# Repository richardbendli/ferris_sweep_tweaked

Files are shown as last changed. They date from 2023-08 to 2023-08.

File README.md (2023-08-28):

# Tweaked Ferris Sweep

A fork of [David Barr's Sweep](https://github.com/davidphilipbarr/Sweep).

| Front | Back |
| :---: | :---: |
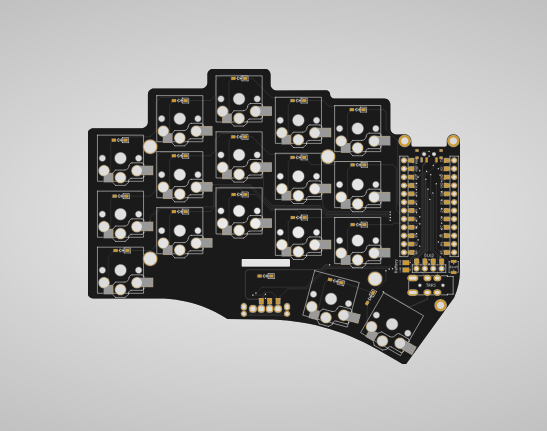
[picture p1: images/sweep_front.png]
front
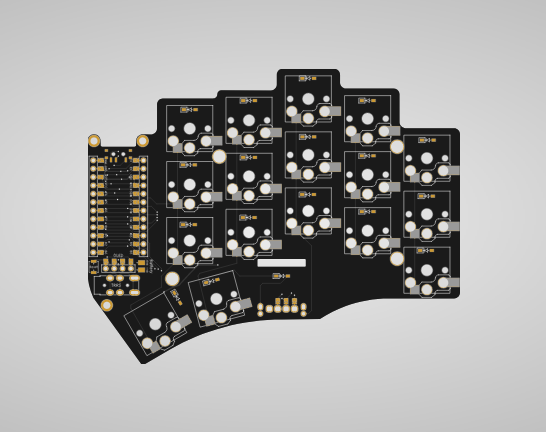
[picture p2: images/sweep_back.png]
back
|  |  |
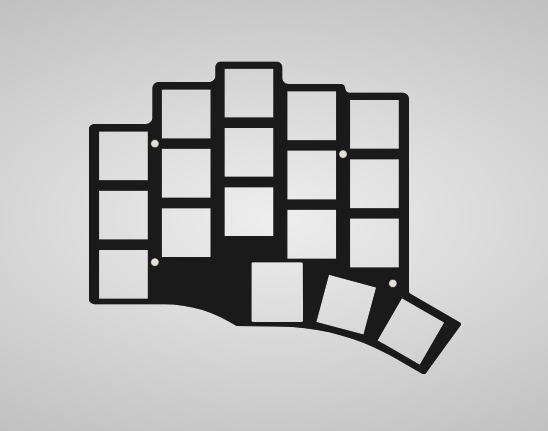
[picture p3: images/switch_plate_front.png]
front
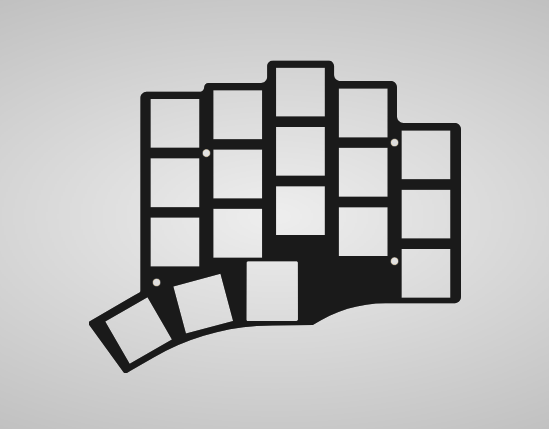
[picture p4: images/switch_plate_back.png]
back
|  |  |
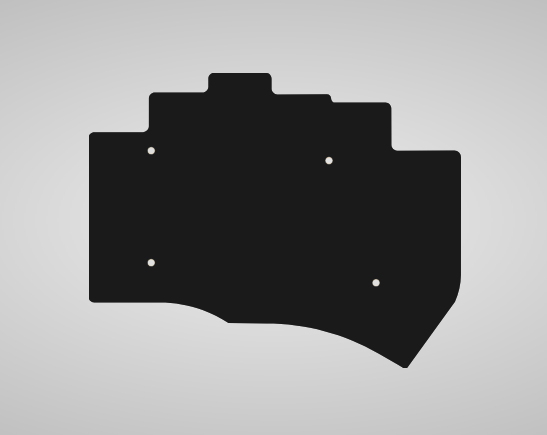
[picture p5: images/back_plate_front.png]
front
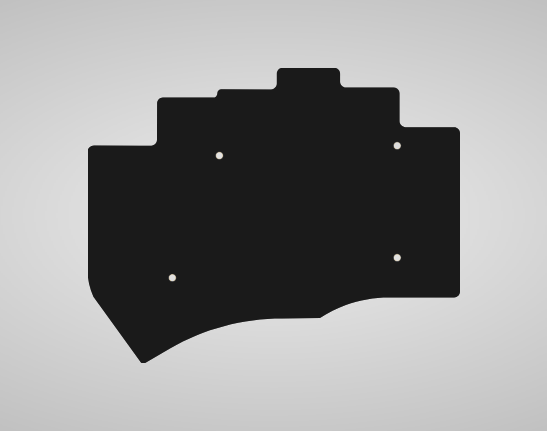
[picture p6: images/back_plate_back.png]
back
|  |  |

### Features

* Low profile Kailh Choc switches
* Hotswap
* Dual side-scrolling encoder
* Oled screens
* Power switch for battery management
* Bluetooth support w/ nice!nano
* Plate style case with mcu cover

### Components list

To build and use this Ferris Sweep you will need:

* 1 × PCB Kit (1.6mm thickness is good)
* 1 × back plate kit (optional, you can go for 1.2mm thickness)
* 2 × promicro compatible boards ( I used the Elite C ) or 2 x nice!nanos.
* 34 × Kailh Choc v1 switches
* 34 × Kailh Choc hotswap sockets (PG1350)
* 34 × keycaps
* 2 × side-scrolling encoders EVQWGD001
* 2 × OLED LCD Display 128x32 SSD1306 (optional)
* 2 × reset switches (optional; B3U-1000P(M))
* Some little rubber feet/bumpers (a minimum of 4 on each side)
* 2 × power switches (wireless only; MSK 12C02)
* 2 × lipo batteries (wireless only; 301230 or 301228)
* 1 × TRRS (not TRS!) cable (wired only)
* 2 × TRRS Jack [PJ-320A] (wired only)
* 1 × USB Cable (depends on your micro-controller choice)

##

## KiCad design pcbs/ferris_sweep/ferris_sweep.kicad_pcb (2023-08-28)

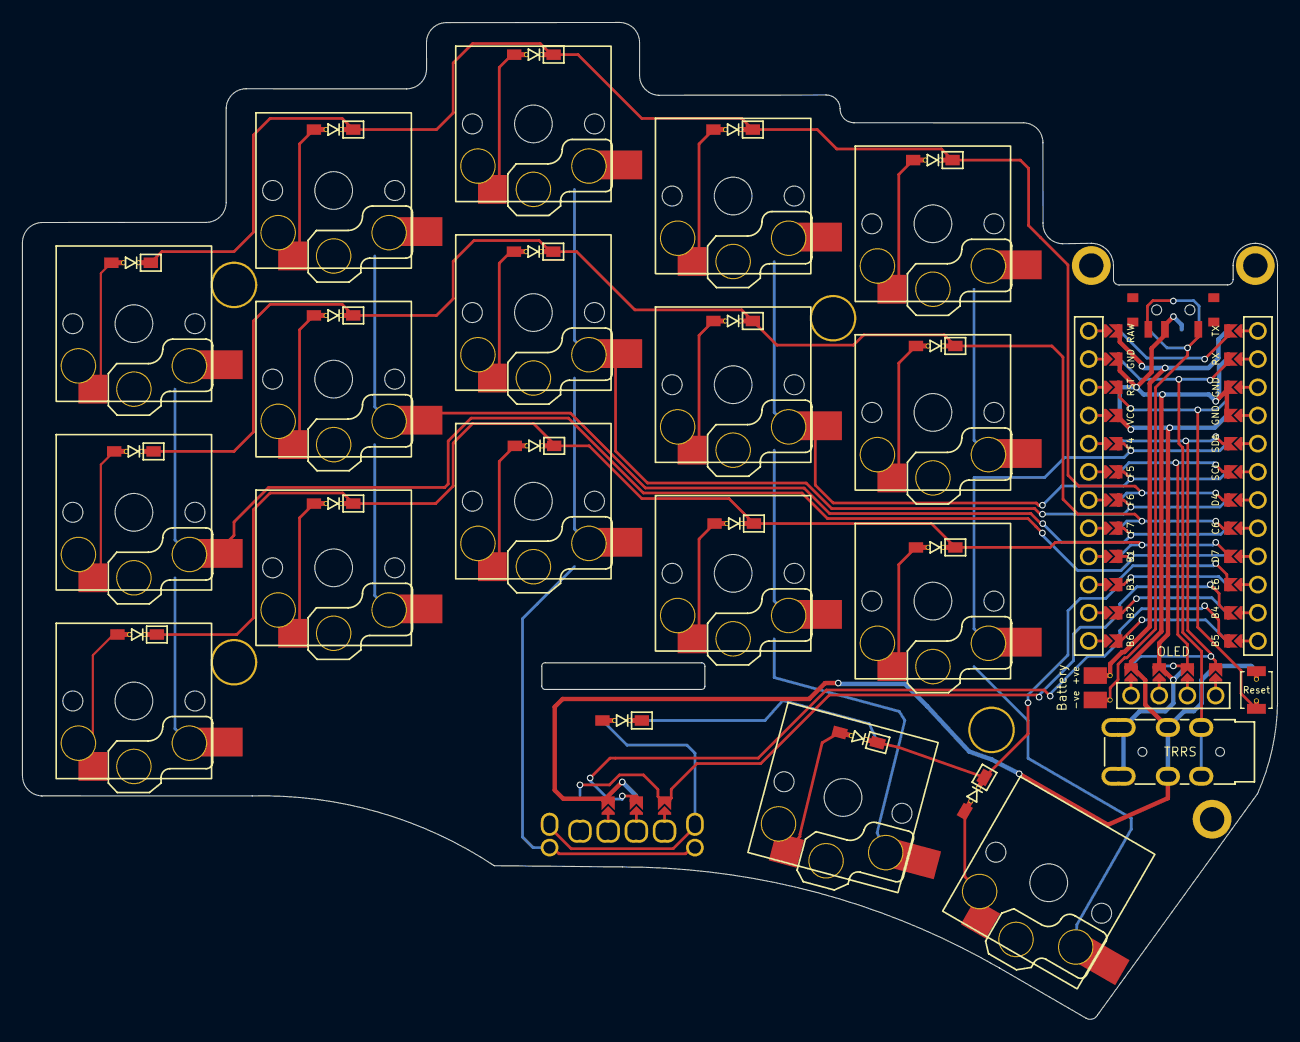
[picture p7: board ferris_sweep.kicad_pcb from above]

Board: 2 copper layers, 113.1 x 89.8 mm, 49 parts (0 on the bottom side), 22 nets.

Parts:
BT1: Battery; Battery_pads_reversible
D1, D2, D3, D4, D5, D6, D7, D8, D9, D10, D11, D12, D13, D14, D15, D16, D17: 1N4148W; D3_SMD
ED1: 1N4148W; D3_SMD
EN2: EVQWGD001; RollerEncoder
H1, H2, H3, H4: M2 Hole; M2_hole_4.2mm
J1: TRRS; TRRS-3pin
O1: OLED; OLED_jumpers
PSW1: Power
RSW1: Reset
Ref**: Val**; M2_hole_3.5mm
Ref**#2, Ref**#3: Val**; M2_hole_3.5mm
SW1, SW2, SW3, SW4, SW5, SW6, SW7, SW8, SW9, SW10, SW11, SW12, SW13, SW14, SW15, SW16, SW17: Choc; Kailh-pg1350-socket-reversible
U1: ProMicro; ProMicro_jumpers

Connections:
GND: EN2.C, J1.C, O1.4, PSW1.2 (B), RSW1.2, U1.3 (GND), U1.4 (GND), U1.23 (GND)
unnamed: D1.2 (A), SW1.2
unnamed: D6.2 (A), SW6.2
unnamed: D11.2 (A), SW11.2
VCC: J1.A, J1.D, O1.3, U1.21 (VCC)
col0: SW1.1, SW6.1, SW11.1, U1.16 (B1)
col1: SW2.1, SW7.1, SW12.1, U1.17 (F7)
col2: EN2.S1, SW3.1, SW8.1, SW13.1, U1.18 (F6)
col3: SW4.1, SW9.1, SW14.1, SW16.1, U1.19 (F5)
col4: SW5.1, SW10.1, SW15.1, SW17.1, U1.20 (F4)
data: J1.B, U1.2 (RX)
eda: EN2.A, U1.11 (B4)
edb: EN2.B, U1.12 (B5)
er0: ED1.2 (A), EN2.S2
raw: BT1.1 (+), U1.24 (RAW)
reset: RSW1.1, U1.22 (RST)
row0: D1.1 (K), D2.1 (K), D3.1 (K), D4.1 (K), D5.1 (K), U1.7 (D4)
row1: D6.1 (K), D7.1 (K), D8.1 (K), D9.1 (K), D10.1 (K), U1.8 (C6)
row2: D11.1 (K), D12.1 (K), D13.1 (K), D14.1 (K), D15.1 (K), U1.9 (D7)
row3: D16.1 (K), D17.1 (K), ED1.1 (K), U1.10 (E6)
sda: O1.1, U1.5 (SDA)
sla: O1.2, U1.6 (SCL)
